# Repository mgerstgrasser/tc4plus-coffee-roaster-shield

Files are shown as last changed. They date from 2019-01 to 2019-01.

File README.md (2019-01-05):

# tc4plus-coffee-roaster-shield

The TC4+ is an Arduino shield designed for temperature measurement, logging and control applications. Both the original TC4 and the TC4+ are designed with coffee roasting applications in mind, but work for a wide range of applications. The TC4+ is an extension of the TC4 shield, adding useful extra such as DC fan motor control and a header for an optional Bluetooth module.

**Features**

- 4-channel, high-resolution thermocouple interface.

- 2-channel SSR drivers for AC loads, and single-channel DC driver for DC fan motors.

- Full compatibility with TC4-based Arduino sketches and established software ecosystem.
- Highly simplified control of popcorn machine based roasters: On-board voltage regulator and DC PWM driver allow popcorn roaster setup with just the TC4+, a single DC power supply and one solid state relay.
- Designed with a high degree of flexibility in mind. Wide range of voltage regulators supported; extra I2C headers for displays and other peripherals; retains all TC4 features and full Arduino pinout.
- Wireless control with optional Bluetooth module. 

**References**
- [Tindie](https://www.tindie.com/products/15798/)
- [Official website](https://coffee.gerstgrasser.net/)
- [Discussion on homeroasters.org](https://forum.homeroasters.org/forum/viewthread.php?forum_id=133&thread_id=5562&pid=65572)
- [TC4 shield and software](https://github.com/greencardigan/TC4-shield)

**License**
These files are available under a [Attribution-NonCommercial-ShareAlike 4.0 International (CC BY-NC-SA 4.0)](https://creativecommons.org/licenses/by-nc-sa/4.0/) license.

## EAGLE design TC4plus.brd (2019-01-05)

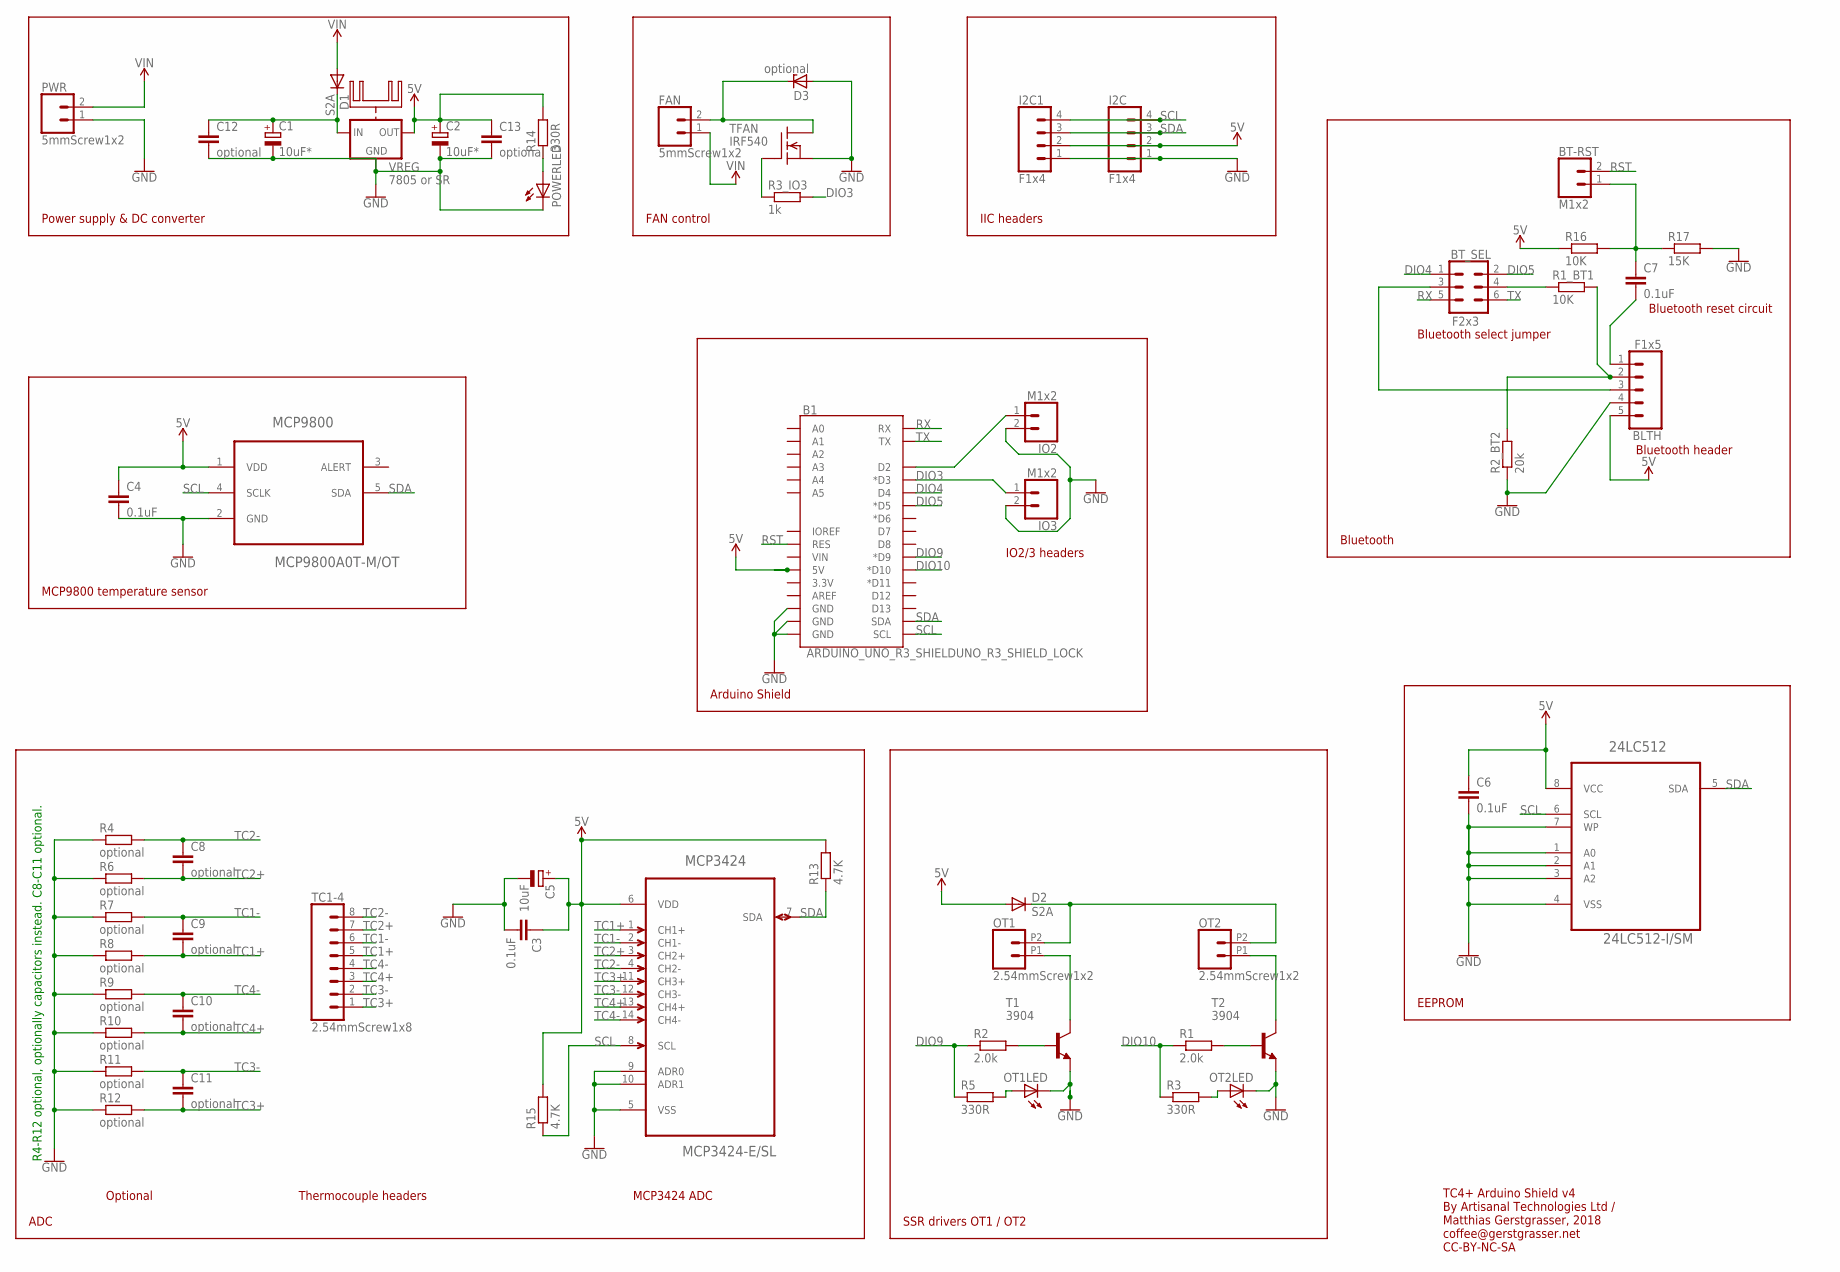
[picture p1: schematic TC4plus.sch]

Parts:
24LC512: 24LC512-I/SM; SOIC127P794X203-8N
B1: ARDUINO_UNO_R3_SHIELDUNO_R3_SHIELD_LOCK; UNO_R3_SHIELD_LOCK
BLTH: F1x5; 1X05_LOCK
BT-RST: M1x2; 1X02
BT_SEL: F2x3; 2X3
C1, C2: 10uF*; E2-5
C3, C4, C6, C7: 0.1uF; C0603
C5: 10uF; A/3216-18R
C8, C9, C10, C11: optional; C0603
C12, C13: optional; C025-025X050
D1, D2: S2A; DO214AA
D3: optional; SMB
FAN: 5mmScrew1x2; SCREWTERMINAL-5MM-2
I2C, I2C1: F1x4; 1X04_LOCK
IO2, IO3: M1x2; 1X02
MCP3424: MCP3424-E/SL; SOIC127P600X175-14N
MCP9800: MCP9800A0T-M/OT; SOT95P280X145-5N
OT1, OT2: 2.54mmScrew1x2; 1X02_2.54_SCREWTERM
OT1LED, OT2LED: LEDCHIP-LED0603; CHIP-LED0603
POWERLED: LEDCHIP-LED0603; CHIP-LED0603
PWR: 5mmScrew1x2; SCREWTERMINAL-5MM-2
R1, R2: 2.0k; R0603
R1_BT1, R16: 10K; R0603
R2_BT2: 20k; R0603
R3, R5, R14: 330R; R0603
R3_IO3: 1k; R0603
R4, R6, R7, R8, R9, R10, R11, R12: optional; R0603
R13, R15: 4.7K; R0603
R17: 15K; R0603
T1, T2: 3904; SOT23-BEC
TC1-4: 2.54mmScrew1x8; 1X08
TFAN: IRF540; TO220
VREG: 7805 or SR; 78XXH

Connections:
5V: 24LC512.8 (VCC), B1.5V, BLTH.5, C2.+, C3.1, C4.1, C5.+, C6.1, C13.1, D2.A, I2C.2, I2C1.2, MCP3424.6 (VDD), MCP9800.1 (VDD), R13.2, R14.2, R15.2, R16.1, VREG.OUT
DC-: D3.C, FAN.2, TFAN.2 (D)
DIO3: B1.D3 (*D3), IO3.1, R3_IO3.2
DIO4: B1.D4, BT_SEL.1
DIO5: B1.D5 (*D5), BT_SEL.2
DIO9: B1.D9 (*D9), R2.1, R5.1
DIO10: B1.D10 (*D10), R1.1, R3.1
GND: 24LC512.1 (A0), 24LC512.2 (A1), 24LC512.3 (A2), 24LC512.4 (VSS), 24LC512.7 (WP), B1.GND@0 (GND), B1.GND@1 (GND), B1.GND@2 (GND), BLTH.4, C1.-, C2.-, C3.2, C4.2, C5.-, C6.2, C12.2, C13.2, D3.A, I2C.1, I2C1.1, IO2.2, IO3.2, MCP3424.5 (VSS), MCP3424.9 (ADR0), MCP3424.10 (ADR1), MCP9800.2 (GND), OT1LED.C, OT2LED.C, POWERLED.C, PWR.1, R2_BT2.1, R4.1, R6.1, R7.1, R8.1, R9.1, R10.1, R11.1, R12.1, R17.2, T1.E, T2.E, TFAN.3 (S), VREG.GND
unnamed: R2.2, T1.B
unnamed: BLTH.2, R1_BT1.2, R2_BT2.2
unnamed: BT_SEL.4, R1_BT1.1
unnamed: BLTH.3, BT_SEL.3
unnamed: R1.2, T2.B
unnamed: R3_IO3.1, TFAN.1 (G)
unnamed: BLTH.1, C7.2
unnamed: OT2LED.A, R3.2
unnamed: POWERLED.A, R14.1
unnamed: OT1LED.A, R5.2
unnamed: BT-RST.1, C7.1, R16.2, R17.1
unnamed: C1.+, C12.1, D1.C, VREG.IN
unnamed: B1.D2, IO2.1
OT1-: OT1.P1 (1), T1.C
OT2-: OT2.P1 (1), T2.C
OT12+: D2.C, OT1.P2 (2), OT2.P2 (2)
RST: B1.RES, BT-RST.2
RX: B1.RX, BT_SEL.5
SCL: 24LC512.6 (SCL), B1.SCL, I2C.4, I2C1.4, MCP3424.8 (SCL), MCP9800.4 (SCLK), R15.1
SDA: 24LC512.5 (SDA), B1.SDA, I2C.3, I2C1.3, MCP3424.7 (SDA), MCP9800.5 (SDA), R13.1
TC1+: C9.2, MCP3424.1 (CH1+), R8.2, TC1-4.5
TC1-: C9.1, MCP3424.2 (CH1-), R7.2, TC1-4.6
TC2+: C8.2, MCP3424.3 (CH2+), R6.2, TC1-4.7
TC2-: C8.1, MCP3424.4 (CH2-), R4.2, TC1-4.8
TC3+: C11.2, MCP3424.11 (CH3+), R12.2, TC1-4.1
TC3-: C11.1, MCP3424.12 (CH3-), R11.2, TC1-4.2
TC4+: C10.2, MCP3424.13 (CH4+), R10.2, TC1-4.3
TC4-: C10.1, MCP3424.14 (CH4-), R9.2, TC1-4.4
TX: B1.TX, BT_SEL.6
VIN: D1.A, FAN.1, PWR.2

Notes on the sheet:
R4-R12 optional, optionally capacitors instead. C8-C11 optional.
Power supply & DC converter
FAN control
IIC headers
MCP9800 temperature sensor
Arduino Shield
IO2/3 headers
Bluetooth
Bluetooth header
Bluetooth reset circuit
Bluetooth select jumper
EEPROM
SSR drivers OT1 / OT2
Thermocouple headers
MCP3424 ADC
Optional
ADC
TC4+ Arduino Shield v4 By Artisanal Technologies Ltd / Matthias Gerstgrasser, 2018 coffee@gerstgrasser.net CC-BY-NC-SA

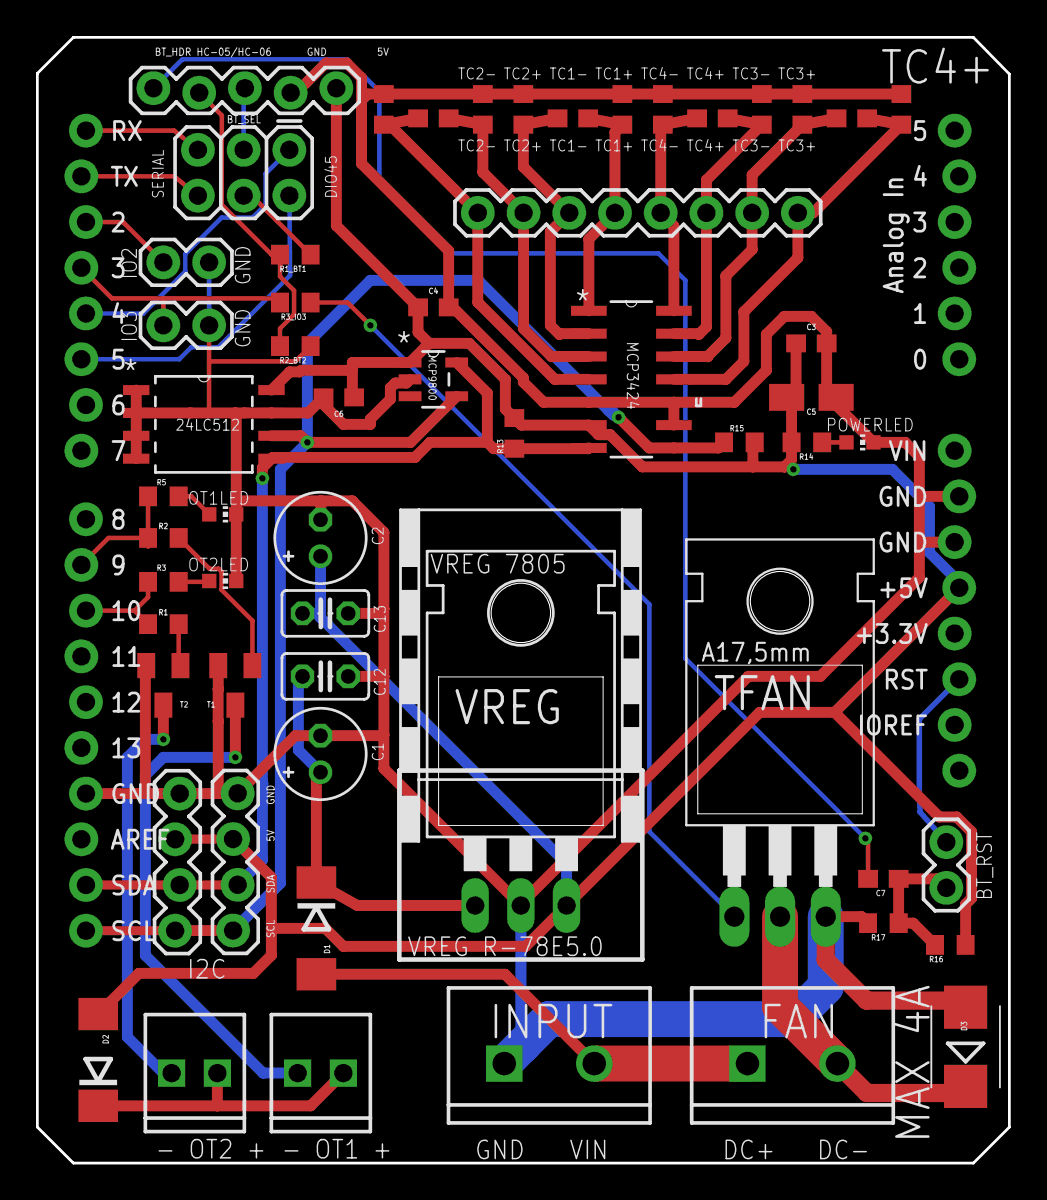
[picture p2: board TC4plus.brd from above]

Board: 2 copper layers, 54.0 x 62.5 mm, 59 parts (0 on the bottom side), 38 nets.

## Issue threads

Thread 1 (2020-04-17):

Can open brd/sch files

rommax-jude, 2020-04-17:
Hi mgerstgrasser,

downloaded board design files in brd/sch, but cadence could not open them and reminded file was corrupted. could you update files or indicate what software may open them. thanks!

mgerstgrasser, 2020-04-17:
Hi rommax-jude, the files were created in EAGLE and should open without issue there.

rommax-jude, 2020-04-19:
Hi Mgerstgrasser,
thank you very much, i used wrong software (Cedence) to open files. problem already gone.&nbsp;

------------------&nbsp;原始邮件&nbsp;------------------
发件人:&nbsp;"mgerstgrasser"<notifications@github.com&gt;;
发送时间:&nbsp;2020年4月17日(星期五) 晚上8:49
收件人:&nbsp;"mgerstgrasser/tc4plus-coffee-roaster-shield"<tc4plus-coffee-roaster-shield@noreply.github.com&gt;;
抄送:&nbsp;"青蛙&amp;天鹅"<50833085@qq.com&gt;;"Author"<author@noreply.github.com&gt;;
主题:&nbsp;Re: [mgerstgrasser/tc4plus-coffee-roaster-shield] Can open brd/sch files (#1)

Hi rommax-jude, the files were created in EAGLE and should open without issue there.

—
You are receiving this because you authored the thread.
Reply to this email directly, view it on GitHub, or unsubscribe.

Closed 2020-04-19.

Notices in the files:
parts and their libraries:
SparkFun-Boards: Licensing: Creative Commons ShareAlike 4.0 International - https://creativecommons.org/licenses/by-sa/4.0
